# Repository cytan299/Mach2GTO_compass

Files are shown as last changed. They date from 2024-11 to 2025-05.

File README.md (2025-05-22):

# Astro-Physics Mach2GTO or Mach1GTO  compass tray

by C.Y. Tan 2024/2025

I have created a 3D printed tray for either a cell phone or a map
compass that can be mounted on a Mach2GTO or Mach1GTO.

## Mach2GTO photos

Here's the photos of the Mach2GTO with the compass tray and attachment.

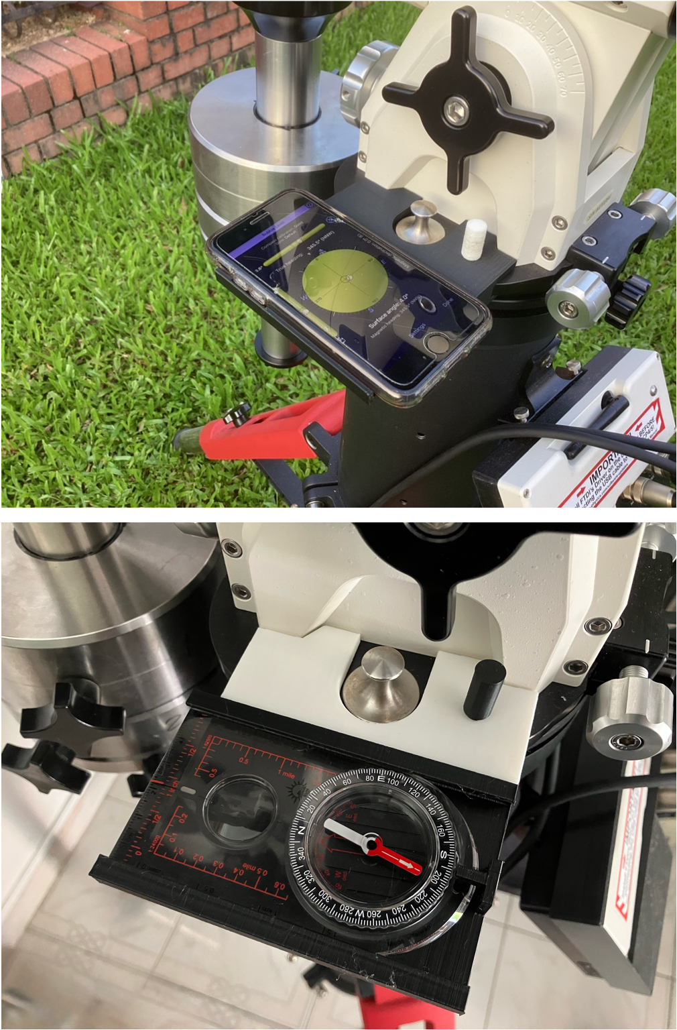
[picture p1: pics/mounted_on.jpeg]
Mach2GTO Tray


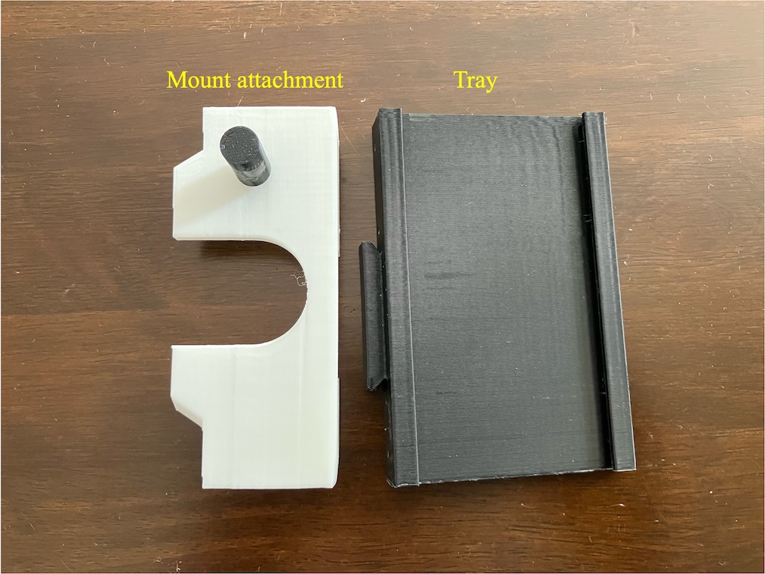
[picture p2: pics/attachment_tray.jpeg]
Mach2GTO Attachment_Tray


## Mach1GTO photos

Here's the photos of the Mach1GTO with the compass tray and attachment.
The Mach1GTO attachment is different from the Mach2GTO
attachment in that it does not have a clamping screw. This attachment
fits into the recess on the East side of the Mach1GTO.

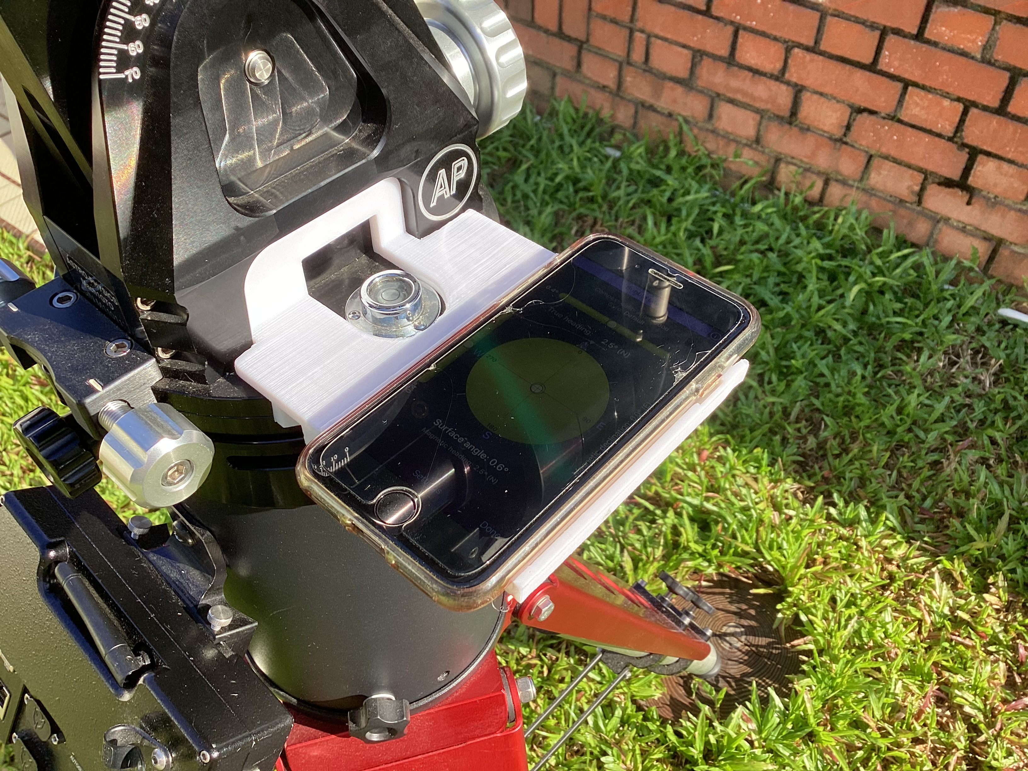
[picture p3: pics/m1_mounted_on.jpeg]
Mach1GTO Tray


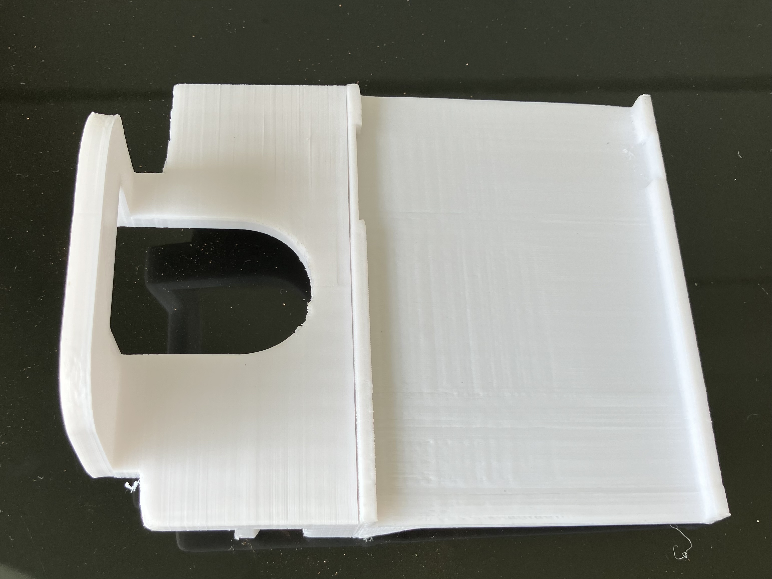
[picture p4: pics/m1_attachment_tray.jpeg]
Mach1GTO Attachement Tray


## Summary

* **Mount attachment** that slides onto the Mach2GTO and
  clamped with a 3D printed screw or into the recess of the  Mach1GTO. 
  
* **Tray** that is is either for a map compass or a cell
  phone. Since cell phones come in many sizes, the user will have to
  modify the OpenSCAD code in _source/mach2gto_compass.scad_ for their
  phone. See README in the _source_ directory for guidance as to what
  to change.
  * The map compass that I used is the _Sun Company ProMap Compass_
    available from [Amazon](https://www.amazon.com/Sun-Company-ProMap-Compass-Orienteering/dp/B0BSB7CK6H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)
	
## Directory structure
* **source** OpenSCAD source code.
* **STL** STL files generated from the OpenSCAD source code. 
* **assembly** Assembly instructions. Only assembly instructions for
  the Mach2GTO are available. Assembly of the Mach1GTO compass tray is
  similar to the Mach2GTO.
* **pics** contains photos used for describing this repository. 

## Support

All the software have been successfully compiled with OpenSCAD version
2024.10.28.

This is unsupported software and hardware. Build at your own peril! :)

You can submit questions or bug reports using the
[issues](https://github.com/cytan299/Mach2GTO_compass/issues) tab 
and then clicking on **New Issue**.

Have fun!

## License

All software is released under GPLv3.

All documentation is released under Creative Commons
Attribution-ShareAlike 3.0 Unported License or GNU Free
Documentation License, Version 1.3

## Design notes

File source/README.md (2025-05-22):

# OpenSCAD source code

by C.Y. Tan 2024/2025

This directory contains the OpenSCAD source codes:
_mach2gto_compass.scad_ and _mach1gto_compass.scad. This code has been
successfully compiled with
[OpenSCAD](https://openscad.org/downloads.html) version 2024.11.04.

* **threads.scad** This library is required for the successful
  compilation of the source code. _threads.scad_ can be downloaded
  from [here](https://github.com/rcolyer/threads-scad).

Since all cell phones have varying dimensions, the user can modify the
code at the top of _mach2gto_compass.scad_ to suit their specific cell
phone with a case. Please note that while the variable names are
iPhone-centric, they are also applicable to Android phones.

  ```cpp
  iphone_l = 140.5; // mm, length of the iPhone includes case. See photo.
iphone_w = 71; // mm, width of the iPhone includes case. See photo.
iphone_H = 10; // mm  height of the iPhone
iphone_button_l = 13; //mm, length of the iPhone button indent. See photo.
iphone_onoff_x = 29; // mm, from reference position. See photo.
iphone_vol_x = 29; // mm, from reference position. See photo.
iphone_vol_l = 26; //mm length of the iPhone volume buttons. See photo
  ```
The photo here

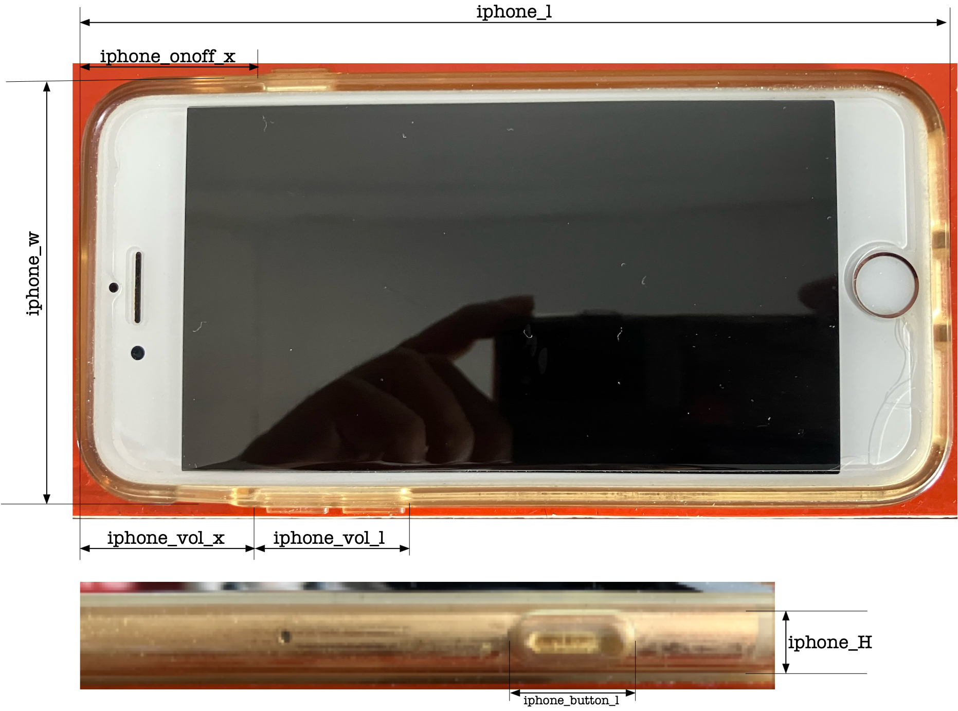
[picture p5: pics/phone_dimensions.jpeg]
phone_dimensions


shows the dimensions that are required for the OpenSCAD program. 

The user can choose what _STL_ files to generate by setting the
following variables to "1". In this example, the user has chosen to
print the clamp screw.

```cpp

// Choose what you want to print by setting it to 1

MAKE_ATTACHMENT = 0;
MAKE_COMPASS_TRAY = 0;
MAKE_IPHONE_TRAY = 0;
MAKE_CLAMP_SCREW = 1;

```

Note: A clamp screw is not needed for the Mach1GTO attachment.

## Support

All the software have been successfully compiled with OpenSCAD version
2024.10.28.

This is unsupported software and hardware. Build at your own peril! :)

You can submit questions or bug reports using the
[issues](https://github.com/cytan299/Mach2GTO_compass/issues) tab 
and then clicking on **New Issue**.

## Copyright

All the software that I have written is copyright 2024 C.Y. Tan.

All software is released under GPLv3.

All documentation is released under Creative Commons
Attribution-ShareAlike 3.0 Unported License or GNU Free
Documentation License, Version 1.3

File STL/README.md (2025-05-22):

# STL files

by C.Y. Tan 2024/2025

These STL files were created with
[OpenSCAD](https://openscad.org/downloads.html) version 2024.11.04
from the source code in the _source_ directory. These files are loaded
into a slicer program like the [Ultimaker
CURA](https://ultimaker.com/software/ultimaker-cura/) generating the
g-code for 3D printing.

## STL files

The STL files for the Mach2GTO and Mach1GTO attachments are
in
* _mach2gto_
  * **clamp_screw.stl** the clamp screw.
  * **mount_attachment.stl** the mount attachment.
* _mach1gto_
  * **mach1gto_attachment.stl** the mount attachment. No clamp screw
    is required.

### Map compass tray stl

Both the Mach2GTO and Mach1GTO compass tray files are called
**compass_tray.stl**. Note: The compass trays of the Mach2GTO and
Mach1GTO are mirror copies of each other.

This tray fits the map compass made by _Sun Company ProMap Compass_
    available from [Amazon](https://www.amazon.com/Sun-Company-ProMap-Compass-Orienteering/dp/B0BSB7CK6H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)
	
### Specialized STL files

I made a phone tray for my iPhone SE called the **iphone_tray.stl**
that fits the SE with case. Note: The iphone trays of the Mach2GTO and
Mach1GTO are mirror copies of each other.

Note:
  Every iPhone generation has different dimensions and
  so the OpenSCAD source code will have to be modified for your
  iPhone. See _source/README.md_ for instructions. Of course, the same
  instructions apply for Android phones as well.
  
## Support

All the software have been successfully compiled with OpenSCAD version
2024.10.28.

This is unsupported software and hardware. Build at your own peril! :)

You can submit questions or bug reports using the
[issues](https://github.com/cytan299/Mach2GTO_compass/issues) tab 
and then clicking on **New Issue**.

## Copyright

All the software that I have written is copyright 2024/2025 C.Y. Tan.

All software is released under GPLv3.

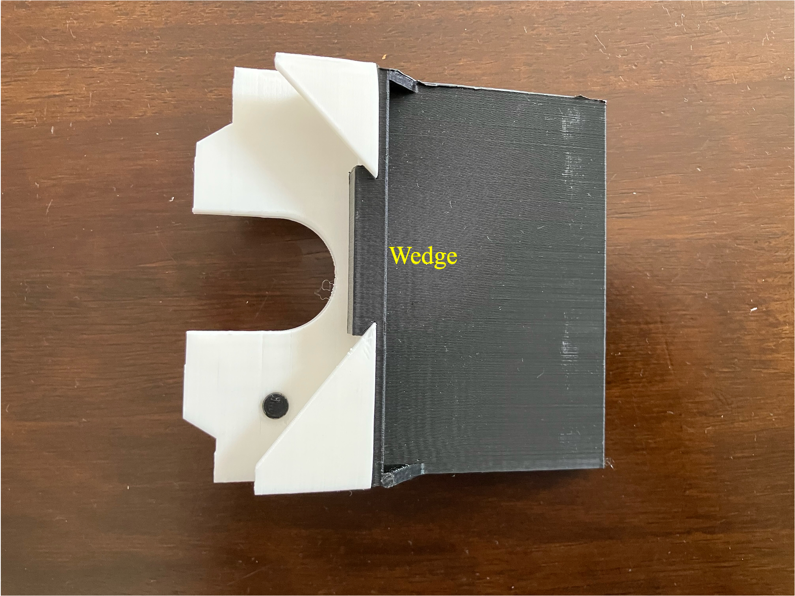
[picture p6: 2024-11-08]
pics/wedge.jpeg

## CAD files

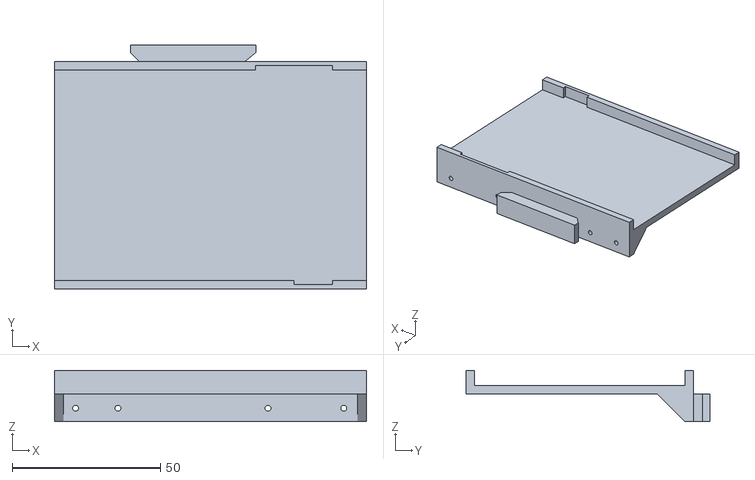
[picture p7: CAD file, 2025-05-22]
STL/mach1gto/iphone_tray.stl
105.4 x 82.6 x 17.2

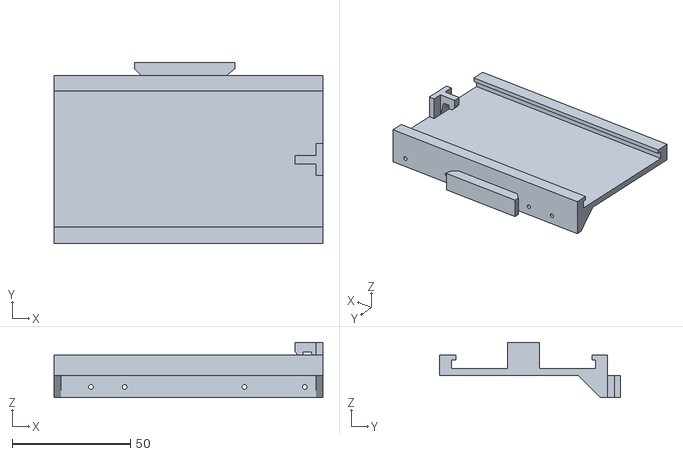
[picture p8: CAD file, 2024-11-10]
STL/mach2gto/map_compass_tray.stl
113.9 x 76.6 x 23.3

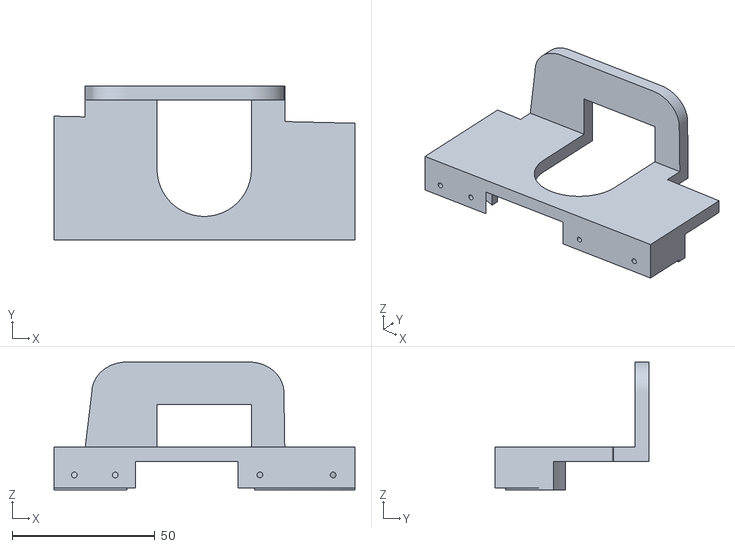
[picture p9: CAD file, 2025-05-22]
STL/mach1gto/mach1gto_attachment.stl
105.4 x 54.0 x 44.8

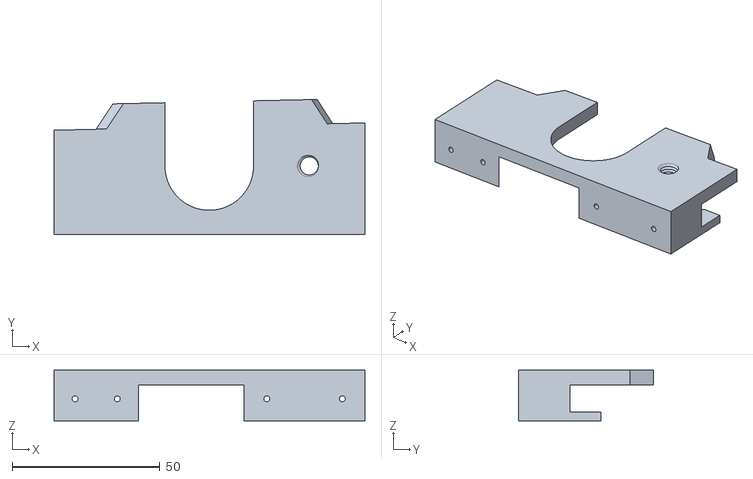
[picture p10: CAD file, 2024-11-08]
STL/mach2gto/mount_attachment.stl
105.4 x 45.8 x 17.2

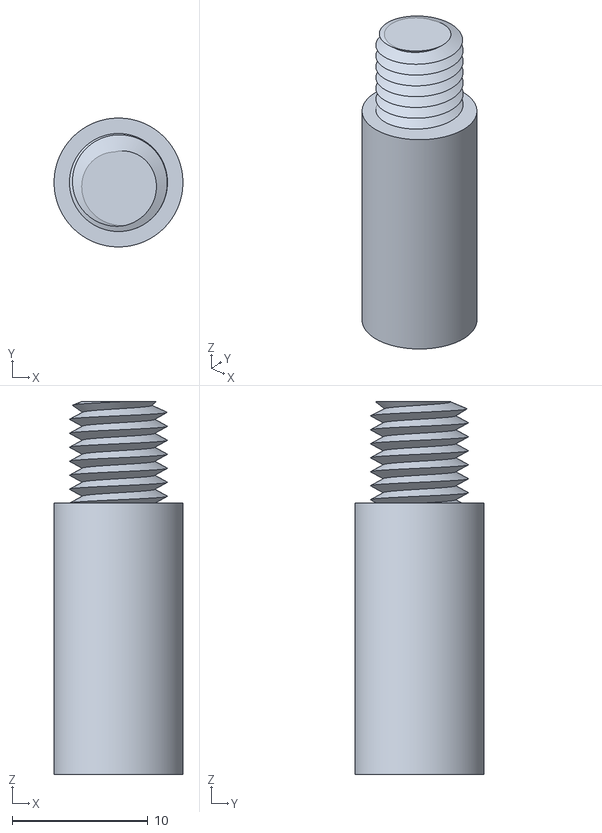
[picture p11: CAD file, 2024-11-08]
STL/mach2gto/clamp_screw.stl
9.50 x 9.50 x 27.5

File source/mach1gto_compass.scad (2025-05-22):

/*
  
    mach1gto_compass.scad is the code to generate a tray for an iPhone
    or map compass
    
    Copyright (C) 2025  C.Y. Tan
    Contact: cytan299@yahoo.com

    This file is part of the Mach1gto compass tray distribution.

    mach1gto_compass.scad is free software: you can redistribute it and/or modify
    it under the terms of the GNU General Public License as published by
    the Free Software Foundation, either version 3 of the License, or
    (at your option) any later version.

    mach1gto_compass.scad is distributed in the hope that it will be useful,
    but WITHOUT ANY WARRANTY; without even the implied warranty of
    MERCHANTABILITY or FITNESS FOR A PARTICULAR PURPOSE.  See the
    GNU General Public License for more details.

    You should have received a copy of the GNU General Public License
    along with mach1gto_compass.scad.  If not, see
    <http://www.gnu.org/licenses/>.

*/

$fn=100;

// Choose what you want to print by setting it to 1

MAKE_ATTACHMENT = 0;  
MAKE_COMPASS_TRAY = 0;
MAKE_IPHONE_TRAY = 1;


// parameters

/*
  This is the definition of an iPhone SE *including* its case.
  Users can change these numbers to match their phone.
*/

iphone_l = 140.5; // mm, length of the iPhone includes case. See photo.
iphone_w = 71; // mm, width of the iPhone includes case. See photo.
iphone_H = 10; // mm  height of the iPhone
iphone_button_l = 13; //mm, length of the iPhone button indent. See photo.
iphone_onoff_x = 29; // mm, from reference position. See photo.
iphone_vol_x = 29; // mm, from reference position. See photo.
iphone_vol_l = 26; //mm length of the iPhone volume buttons. See photo


/*
  For heavier phones, the gusset length can be increased
*/

gusset_l = 0; //mm


// Do not change the following parameters

base_t = 5; // mm, base thickness

// rectangular part of the base
base_rect_x = 105.4; //mm
base_rect_y0 = 35.35; // mm, left top edge
base_rect_y1 = 37.8382; // mm, right top edge

// dy translation so that the nothing actually hits the base of the Mach1 mount
dyR = 5.5515; //mm

// slot
slot_r = 16.5; //mm

// bracket
bracket_space = 9.25;//mm spacing
bracket_t = 3; //mm thickness of bracket wall

// screw holes
screw_r = 1; // mm

// curved wall
curved_wall_x0 = 2.9004;
curved_wall_y0 = 89.8863;
curved_wall_inner_r = 90; //mm
curved_wall_outer_r = 93; //mm
curved_wall_h = 10; //mm

// back wall
back_wall_l = 69.8927; //mm
back_wall_h = 29.8;
back_wall_t = base_t;
back_wall_curve_r = 7;


// compass tray length
compass_tray_l = base_rect_x + 8.5; //mm, length of the compass tray

module make_base()
{
  union(){

    //  the polygon shape of the base that does not have angled walls
    //  or slots yet or wings
    translate([-base_rect_x/2,-dyR,0]){
      linear_extrude(height=base_t, v=[0,0,1], center=false){

	polygon(points=[[0,0.00],[105.4, 0],[105.4, 40.9015],
			[80.8176,41.4818],[80.8176,53.9502],
			[10.9250,53.9502], [10.9250, 43.1318],
			[0,43.3897],[0,0]]);

	
      } // linear_extrude
    } // translate   



  }// union
}

module make_back_wall()
{
  translate([-41.7750 ,  48.3987, base_t]){
    rotate([90, 0, 0]){
      union(){
	difference(){

	  linear_extrude(height=back_wall_t, v=[0,0,1], center=false){

	    polygon(points=[[0,0.00],[back_wall_l, 0],[69.4166, back_wall_h],
			    [3.5817,back_wall_h],[0,0]]);

	
	  } // linear_extrude	  

	  block_l = 14.5903;
          //remove the top edges for rounding
	  union(){
            //left top edge
	    translate([0, 19.1, -2*back_wall_t]){
	      cube([block_l, 2*block_l, 4*back_wall_t], center = false);
	    }

	    block_r = 12.6;
            // right top edge
	    translate([57.2927, 19.1, -2*back_wall_t]){
	      cube([block_r, 2*block_r, 4*back_wall_t], center = false);
	    }

	    } // union


	} // difference

        // add in the rounded edges which are ellipses
	// create ellipses by changing scale

        // top left rounded edge

	lc_r = 12.2946;
	translate([14.5903, 19.1, back_wall_t/2]){
	  scale([1,10.7/lc_r, 1]){
	    cylinder(r=lc_r, h=back_wall_t, center=true);
	  }
	}

	//top right rounded edge
	rc_r = 12.2949;
	translate([57.2927, 19.1, back_wall_t/2]){
	  scale([1, 10.7/rc_r, 1]){
	    cylinder(r=rc_r, h=back_wall_t, center=true);
	  }
	}

      } // union
    } // rotate
  } // translate
}

module make_slot()
{
  // coordinate of the circular slot  
  x0 = -0.08; 
  y0=19.24; 

  union(){

    // round hole
    translate([x0,y0, 0]){
      cylinder(r=slot_r, h = 4*base_t, center=true );
    }

    // the straight edges

    translate([x0,2*slot_r+y0, 0]){
      cube([2*slot_r, 4*slot_r, 8*base_t], center=true);
    }
    
  }
}

module make_curved_wall()
{
  difference(){
    translate([curved_wall_x0, curved_wall_y0, -curved_wall_h/2]){
      difference(){
	cylinder(r=curved_wall_outer_r, h = curved_wall_h, center = true);
	// remove in inside of the cylinder
	cylinder(r=curved_wall_inner_r, h = 4*curved_wall_h, center = true);
      }

    } // translate

    // remove stuff outside the base
    // outside right wall
    translate([2*curved_wall_outer_r + base_rect_x/2, 2*curved_wall_outer_r, 0]){
      cube([4*curved_wall_outer_r, 4*curved_wall_outer_r, 4*curved_wall_h], center=true);
    }
    // outside left wall
    translate([-2*curved_wall_outer_r - base_rect_x/2, 2*curved_wall_outer_r, 0]){
      cube([4*curved_wall_outer_r, 4*curved_wall_outer_r, 4*curved_wall_h], center=true);
    }

    // left over curved wall
    translate([0,3*curved_wall_outer_r,0]){
      cube([4*curved_wall_outer_r, 4*curved_wall_outer_r, 4*curved_wall_h], center=true);
    }

    // remove stuff to not block the dovetail

    dovetail_w = 42.5640+2; //mm
    wall_t = curved_wall_outer_r - curved_wall_inner_r;

    translate([-27.1174,-dyR,-2*curved_wall_h]){
      cube([dovetail_w, 4*wall_t, 4*curved_wall_h], center=false);
    }
    
  } //union
    

}

module make_brackets()
{

  // left bracket spacer
  translate([-24.1174, -dyR, -bracket_space]){
    union(){
      // space part
      linear_extrude(height=bracket_space, v=[0,0,1], center=false){
	polygon(points=[[0,0],
			[-28.5826, 0], [-28.5826,9.9321],
			[-25.5826, 9.9321],[-25.5826,3],
			[-3,3], [0,0]]);
      }


    } // union
  } // translate

    
  // right bracket spacer
  translate([11.7517, -dyR, -bracket_space]){
    union(){
      // spacer part
      linear_extrude(height=bracket_space, v=[0,0,1], center=false){
	polygon(points=[[0,0],
			[3.695, 3.0], [37.9483,3],
			[37.9483, 17.5009],[40.9483,17.5009],
			[40.9483,0], [0,0]]);
      }

	
    } // union
      
  } // translate 

}

module make_screw_hole(pos)
{
  translate(pos){
    rotate([90,0,0]){
      cylinder(r=screw_r, h=4*bracket_t, center=true);
    }    
  }
}

module make_bracket_screw_holes()
{
  make_screw_hole([-31.2630,0,-4.75]);
  make_screw_hole([-45.5542,0,-4.75]);
  make_screw_hole([19.4295,0,-4.75]);
  make_screw_hole([45.0222,0,-4.75]);      
}


module make_compass_tray()
{
  dtol = 0.025;
  
  translate([base_rect_x/2,-bracket_t,0]){
    rotate([0,-90,0]){
      linear_extrude(height=compass_tray_l, v=[0,0,1], center=false){
	polygon(points=[[0,0], [-bracket_space, 0],
			[-bracket_space, bracket_t],
			[8.75,bracket_t],[8.75, -3.5],
			[6.75,-3.5],[6.75, -2+dtol],
			[bracket_t,-2+dtol],
			[bracket_t,-63-dtol],
			[6.75,-63-dtol],
			[6.75, -61], [8.75,-61],
			[8.75,-68],[0,-68],
			[0,0]
			]);
      }
    }
  }
}

module make_compass_tray_dovetail()
{
  dtol = 0.025;
  
  translate([-24.1174, 0, -(bracket_t*0 + bracket_space)]){
    linear_extrude(height=bracket_space, v=[0,0,1], center=false){
      polygon(points=[[dtol,0],
		      [-3+dtol, bracket_t], 
		      [-3+dtol, 5.5515],
		      [39.5640-dtol, 5.5515], [39.5640-dtol,bracket_t],
		      [35.8691-dtol, 0],
		      [dtol,0]
		      ]);
    }
  }
}

module make_compass_tray_gussets()
{
  dx = compass_tray_l - base_rect_x; // extra length of the tray
  union(){
    translate([bracket_t-base_rect_x/2-dx,-bracket_t,0]){
      rotate([0,-90,0]){
	linear_extrude(height=bracket_t, v=[0,0,1], center=false){
	  polygon(points=[[0,0],
			  [0, -(bracket_space + gusset_l)],
			  [-bracket_space, -gusset_l],
			  [-bracket_space, 0],
			  [0,0]
			  ]);
	}
      }
    }

    translate([bracket_t + base_rect_x/2 - bracket_t,-bracket_t,0]){
      rotate([0,-90,0]){
	linear_extrude(height=bracket_t, v=[0,0,1], center=false){

	  polygon(points=[[0,0],
			  [0, -(bracket_space + gusset_l)],
			  [-bracket_space, -gusset_l],
			  [-bracket_space, 0],
			  [0,0]
			  ]);	  
	}
      }
    }
  }    
}

module make_compass_tray_catch()
{
  catch_x_w = bracket_t; // x width
  catch_y_w = 3.6; // y width
  catch_z_w = 11.1; // z height

  catch_ypos = 35.5; // measured

  echo("******yyy = ", catch_y_w/2 - catch_ypos);

  union(){
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

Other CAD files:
STL/mach1gto/compass_tray.stl
STL/mach2gto/iphone_tray.stl
source/mach2gto_compass.scad

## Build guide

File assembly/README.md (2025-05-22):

# Assembly instructions

by C.Y. Tan 2024

This directory contains the assembly instructions.

## Copyright

All the documentation that I have written is copyright 2024 C.Y. Tan.

All documentation is released under Creative Commons
Attribution-ShareAlike 3.0 Unported License or GNU Free
Documentation License, Version 1.3

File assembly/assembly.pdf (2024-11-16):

# Mach2GTO compass tray assembly guide

## C.Y. Tan Nov 16, 2024

2 | Mach2GTO compass tray | November 16, 2024

# License

## Copyright 2024 C.Y. Tan This document is licensed under Creative Commons Attribution-ShareAlike 3.0 Unported License. To view a copy of this license, visit http://creativecommons.org/lice nses/by-sa/3.0/ (http://creativecommons.org/licenses/by-sa/3.0/)

3 | Mach2GTO compass tray | November 16, 2024

# Assembly

## Assembly of the Compass Tray

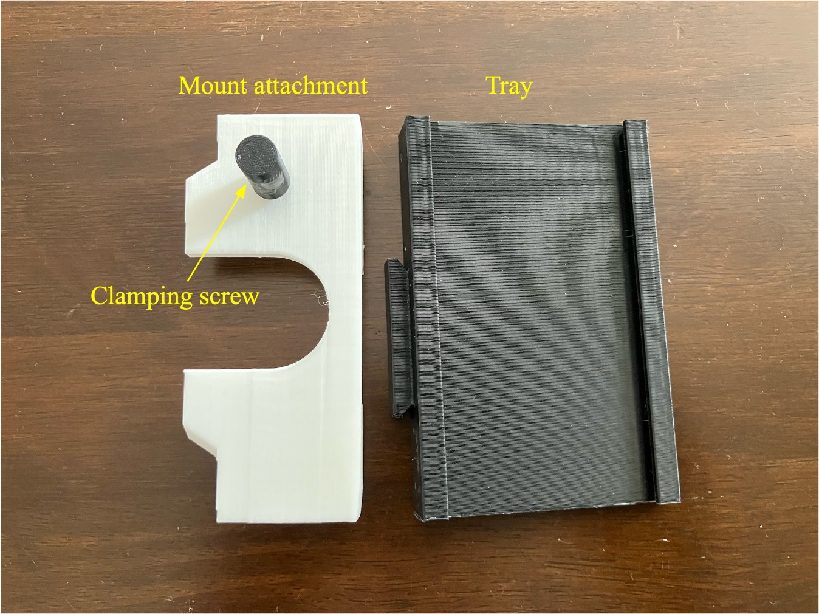
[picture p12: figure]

4 | Mach2GTO compass tray | November 16, 2024

# 3D print

## The mount attachment, tray and clamping screw are printed using the STL files in the STL directory or separately generated by the user with the source code

mach2gto_compass.scad.

Note 1: the Tray shown here is from an early prototype. Low quality” printing was selected in CURA.

For the final prints, I have set “Standard Quality” for both the clamping screw and mount attachment; “Low quality” for the tray.

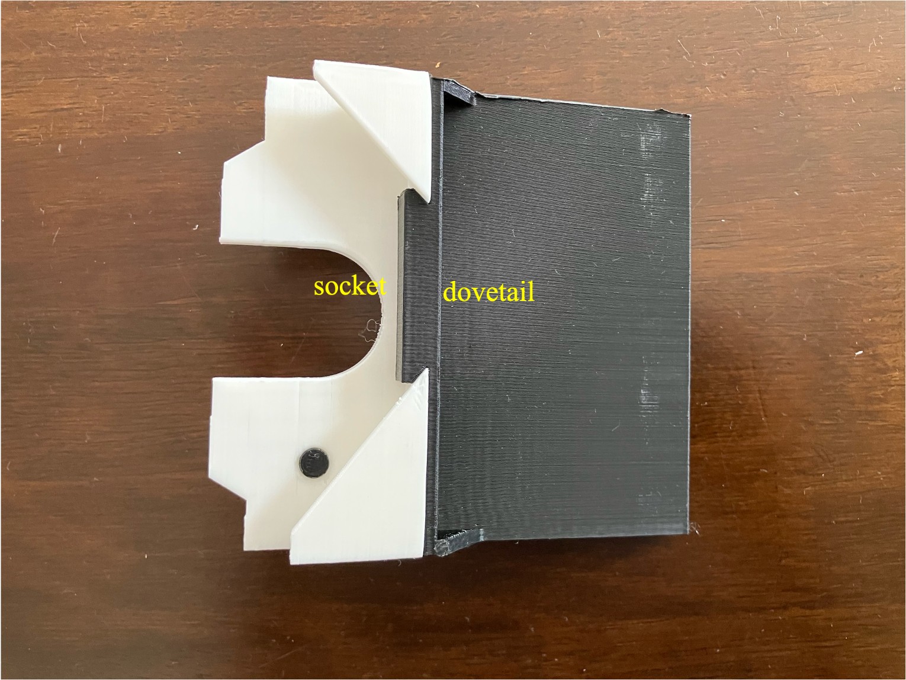
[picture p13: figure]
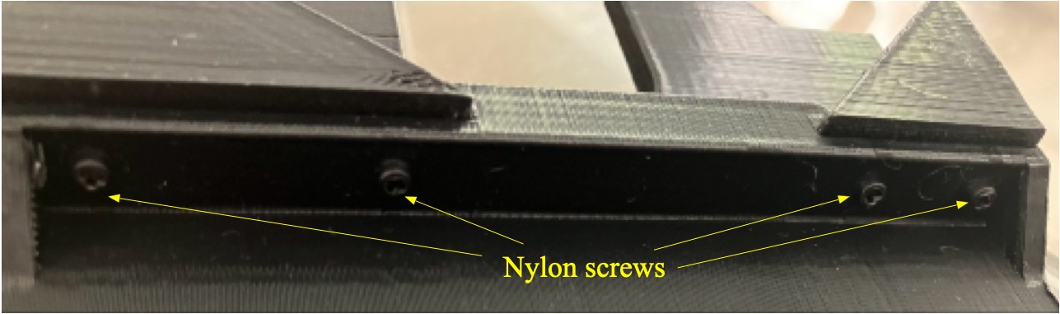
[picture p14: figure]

5 | Mach2GTO compass tray | November 16, 2024

# Assembly

## The mount attachment and the tray are attached together by sliding the dovetail on the tray into the socket in the

mount attachment: | The dovetail and socket combination has a good friction fit and does not need glue or screws if the phone or compass are light. Superglue can be used to permanently join these two parts together.
| However, I have provided holes in both the mount attachment and the tray. I used 2-56 screws to thread the holes. Nylon screws are then used to join the two parts together.

Do NOT use steel screws because they are magnetic! Stainless steel, Brass or Nylon screws should be used.

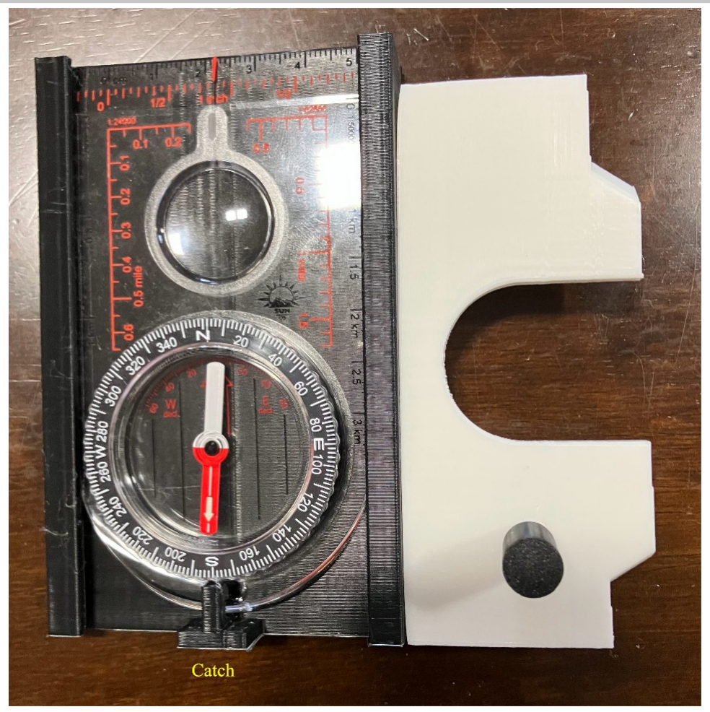
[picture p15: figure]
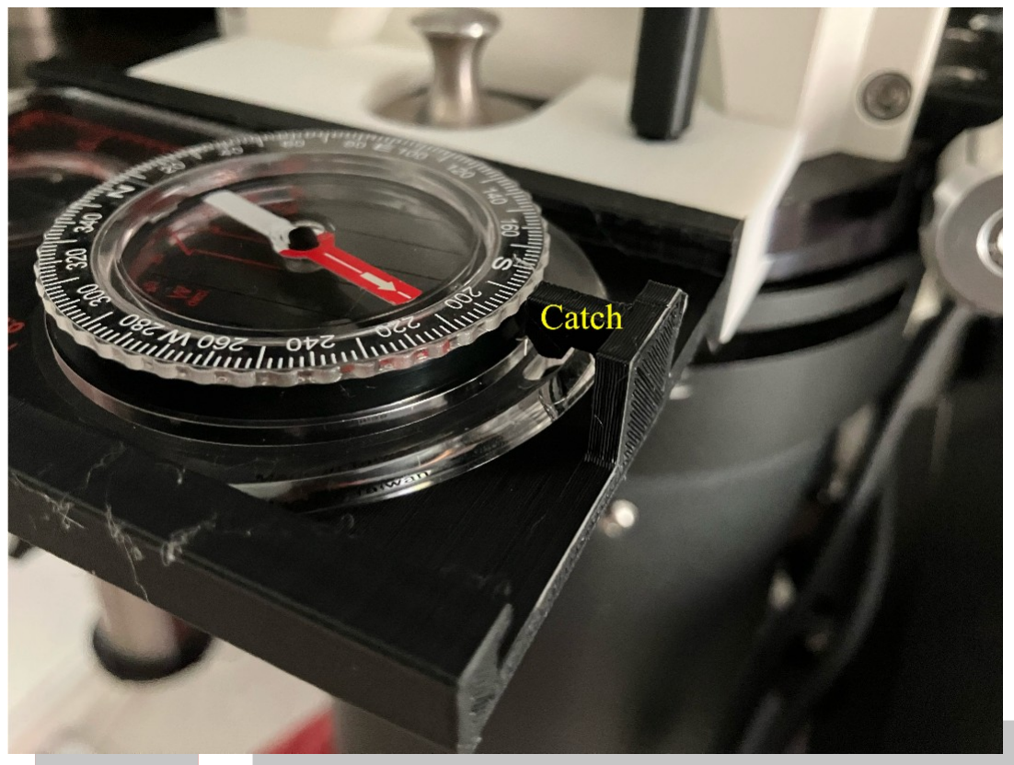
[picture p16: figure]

6 | Mach2GTO compass tray | November 16, 2024

# Map compass installation

The map compass is slid with the compass end first into the tray so that the “Catch” can catch it.

The Catch stops the compass from sliding off the tray but also allows it to be freed by the user if necessary.

In this example, the tray has not been permanently joined to the mount assembly because the compass is very light. The friction fit between the tray and the mount assembly is strong enough to hold them together.

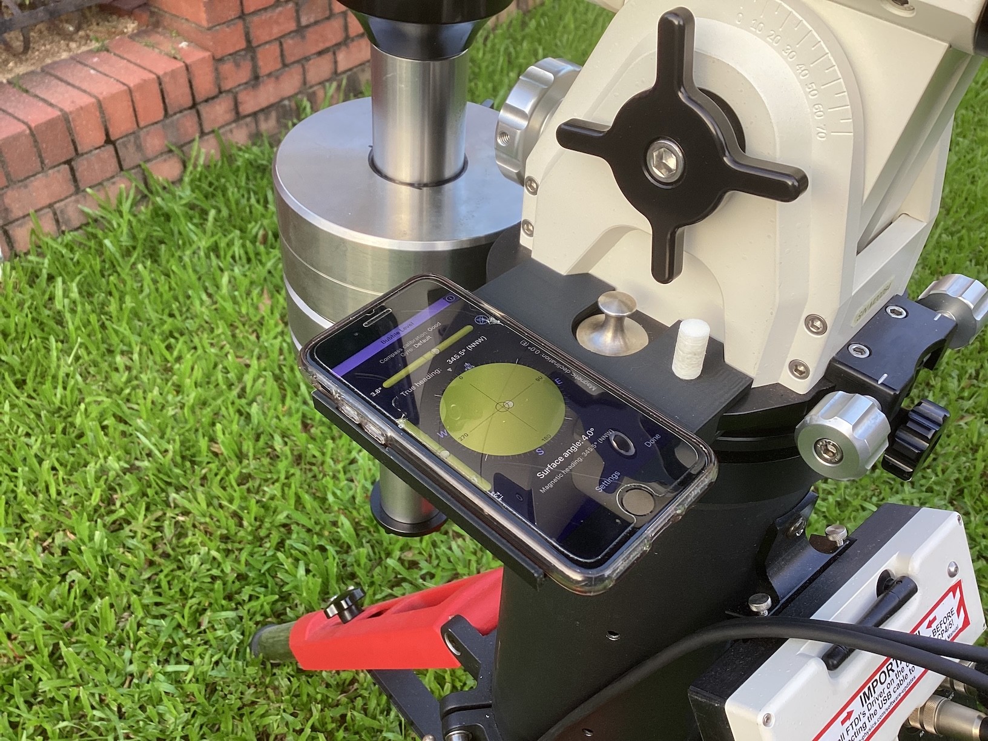
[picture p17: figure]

7 | Mach2GTO compass tray | November 16, 2024

# Mounting

As shown in the photo, the compass tray is slid onto the Mach2GTO. The clamping screw is tightened to stop it from moving.

The shape of the mount attachment is such that it perfectly fits into the recess of the Mach2GTO. This tight fit ensures reproducibility between installs.

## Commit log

2024-11-08 Updated README.md. Added COPYING.TXT, pics and source.
    [mach2gto_compass.scad]
2024-11-08 Updated README.md and source/mach2gto_compass.scad. Added photos in pics. Added README.md in source.
    [mach2gto_compass.scad]
2024-11-08 Updated README.md, source/README.md. Added assembly and more pics.
2024-11-08 Updated README.md, assembly/README.md, source/README.md and source/mach2gto_compass.scad. Added STL.
    [clamp_screw.stl, hiking_compass_tray.stl, iphone_tray.stl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]
2024-11-08 Updated STL/README.md and renamed STL/mount_assembly.stl.
    [mount_attachment.stl]
2024-11-08 Updated STL/README.md
2024-11-10 Updated: source/mach2gto_compass.scad: Added catch for the compass tray. Updated compass tray size to better fit the ProMap compass. Updated STL/hiking_compass_tray.stl
    [hiking_compass_tray.stl, mach2gto_compass.scad]
2024-11-11 Replaced all occurrences of 'hiking' with 'map' to more accurately reflect the type of compass that I used.
    [mach2gto_compass.scad, map_compass_tray.stl]
2024-11-13 STL/README.md: Fixed grammar and added a line about Android.
2024-11-16 Updated source /README.md to reference Android. Updated assembly.pdf: Changed occurrences of wedge to dovetail. Updated mach2gto_compass.scad: Changed occurrences of wedge to dovetail.
    [mach2gto_compass.scad]
2024-11-17 Updated REAME.md to show both iphone and map compass mounted on mach2gto. Added and removed photos that show compass tray mounted.
2025-05-22 Added Mach1GTO compass tray source, pics and STL files. Updated all README.md's to include Mach1GTO descriptions.
    [clamp_screw.stl, compass_tray.stl, iphone_tray.stl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]
